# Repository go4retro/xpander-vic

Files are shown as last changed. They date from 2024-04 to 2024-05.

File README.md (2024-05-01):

# X-Pander VIC

## Introduction

Cousin to the X-Pander 3 for the C64/SX/C128/C128D, X-Pander VIC opens up a wealth of expansion options for your Commodore VIC-20/VIC-1001. This design continues on tradition of vintage designs like the CardCo Cardboard, while adding more granular controls over select lines like the CMD EX-3/EX2+1 for the C64. The X-Pander VIC offers the following features:

- Individually-selectable expansion ports
- sPower indicators for each port
- Ability to swap IO select lines ports
- Easily accessed piano-style configuration switches
- Top-loading or back-loading terminal port.
- Terminal port can accommodate 2 cartridges at the same time*
- Reset switch

\* Both top and back-loading options for terminal port share a single set of configuration switches, requiring 2 cartridges that can coexist without configuration.

## Requirements

- Commodore VIC-20 or VIC-1001

## Purchase

The current X-Pander VIC design is not yet available, but an older model (which requires some modification by the consumer can be purchased at the [RETRO Innovations Online Store](https://store.go4retro.com/non-functional-goodies/).

## Technical Details

X-Pander VIC creates a “passive” cartridge port “bus”, with switches on the following lines:

- Power (2 switches)
- IO2
- IO3
- RAM1
- RAM2
- RAM3
- BLK1
- BLK2
- BLK3
- BLK5
- AUDIO

Additionally, all ports except the first contain jumpers allowing one to “swap”  IO2 and IO3. This can be used to move a peripheral cartridge (like a  serial card or ethernet card) normally residing at IO3 to the  alternative IO3 position so that it can coexist with another IO cartridge. Jumpers are provided, but the jumper  pins can be removed and replaced with a subminiature DPDT (double pole,  double throw) switch.

## Support

Expansion port cartridges were not normally designed to coexist with  other cartridges. Thus, it is impossible to detail the nearly infinite  combinations and whether each works or not. Also, since the “bus”  places additional load on the unbuffered expansion port IO lines,  cartridges that are susceptible to signal degradation may not work with  X-Pander VIC, even when installed alone.

Some helpful hints:

- Always insert or remove X-Pander VIC with the system port off
- Clean cartridge contacts before installation
- Switches are “on” when depressed. Normally, all switches can be left in the “on” position
- IO2/IO3 swap jumpers must be moved as a pairs

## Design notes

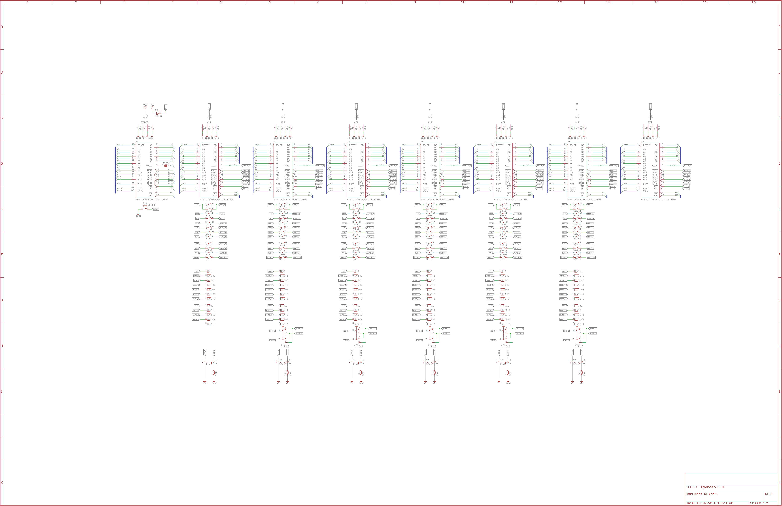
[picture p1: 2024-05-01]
pcb/Xpander6-VIC Schematic.png

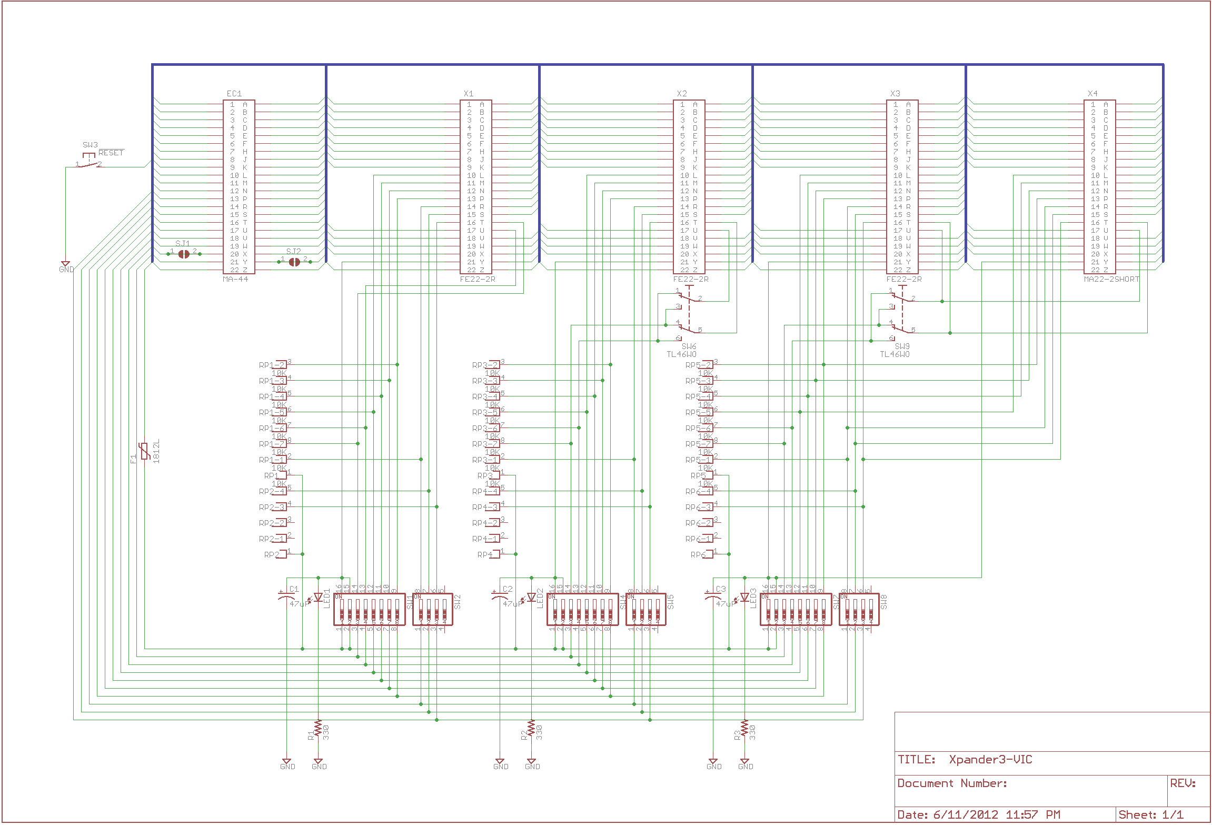
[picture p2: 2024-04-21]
pcb/Xpander3-VIC Schematic.png

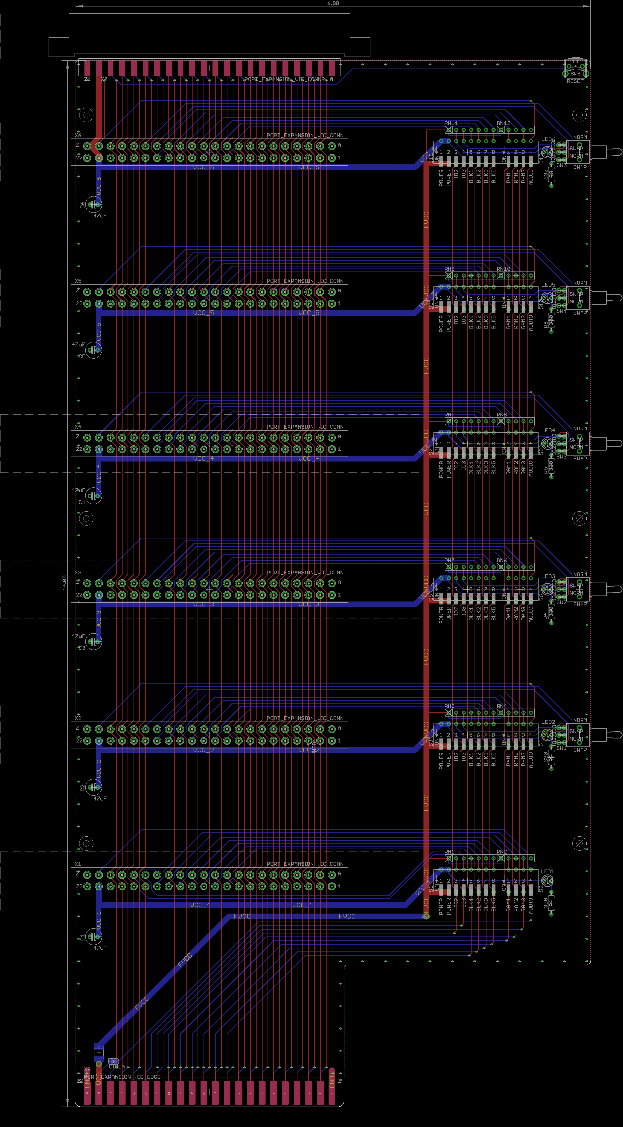
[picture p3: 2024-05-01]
pcb/Xpander6-VIC PCB.png

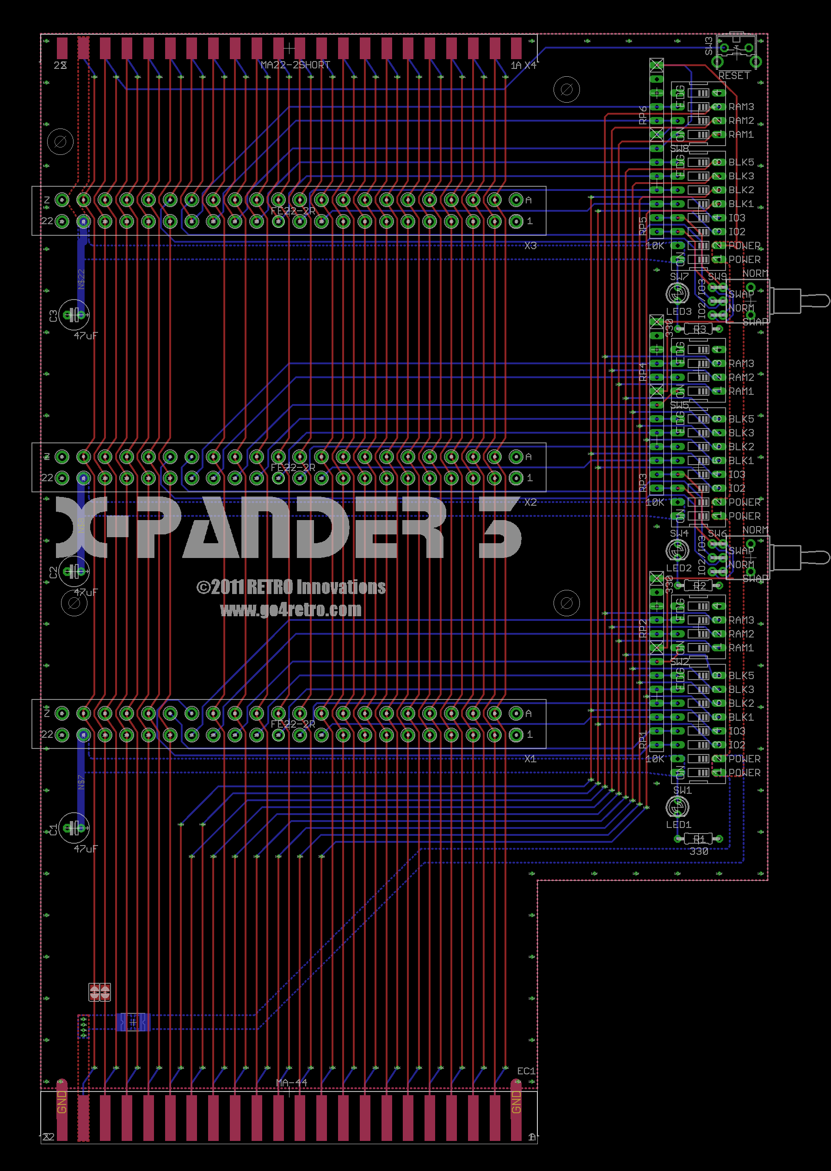
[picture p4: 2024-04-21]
pcb/Xpander3-VIC PCB.png

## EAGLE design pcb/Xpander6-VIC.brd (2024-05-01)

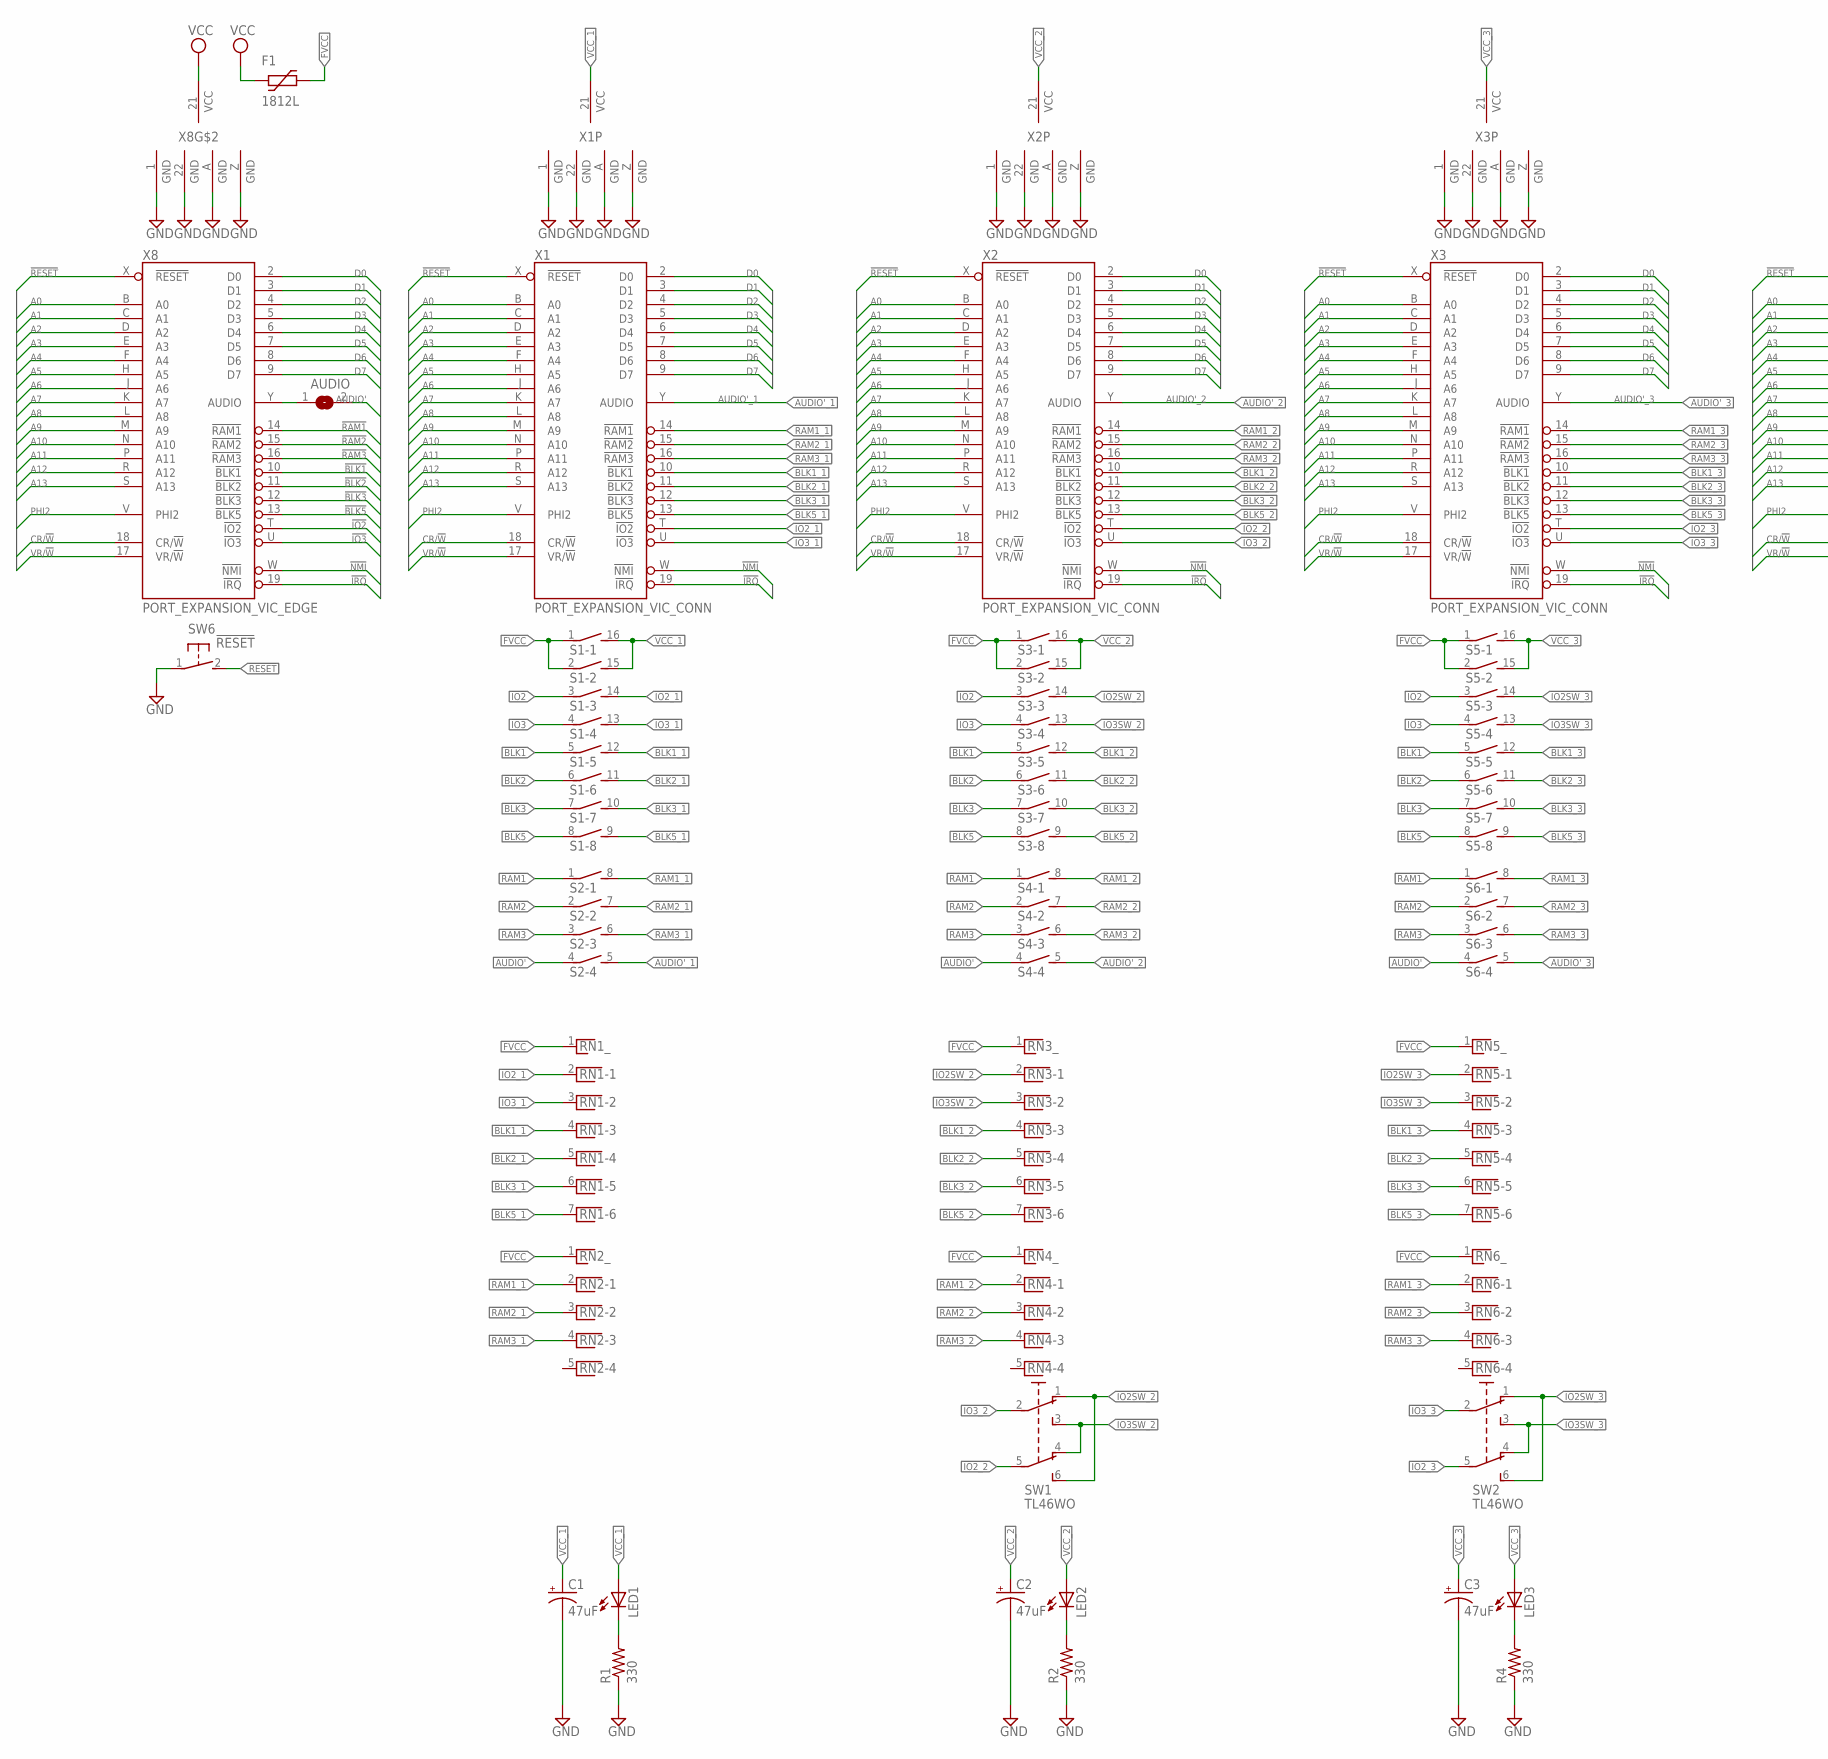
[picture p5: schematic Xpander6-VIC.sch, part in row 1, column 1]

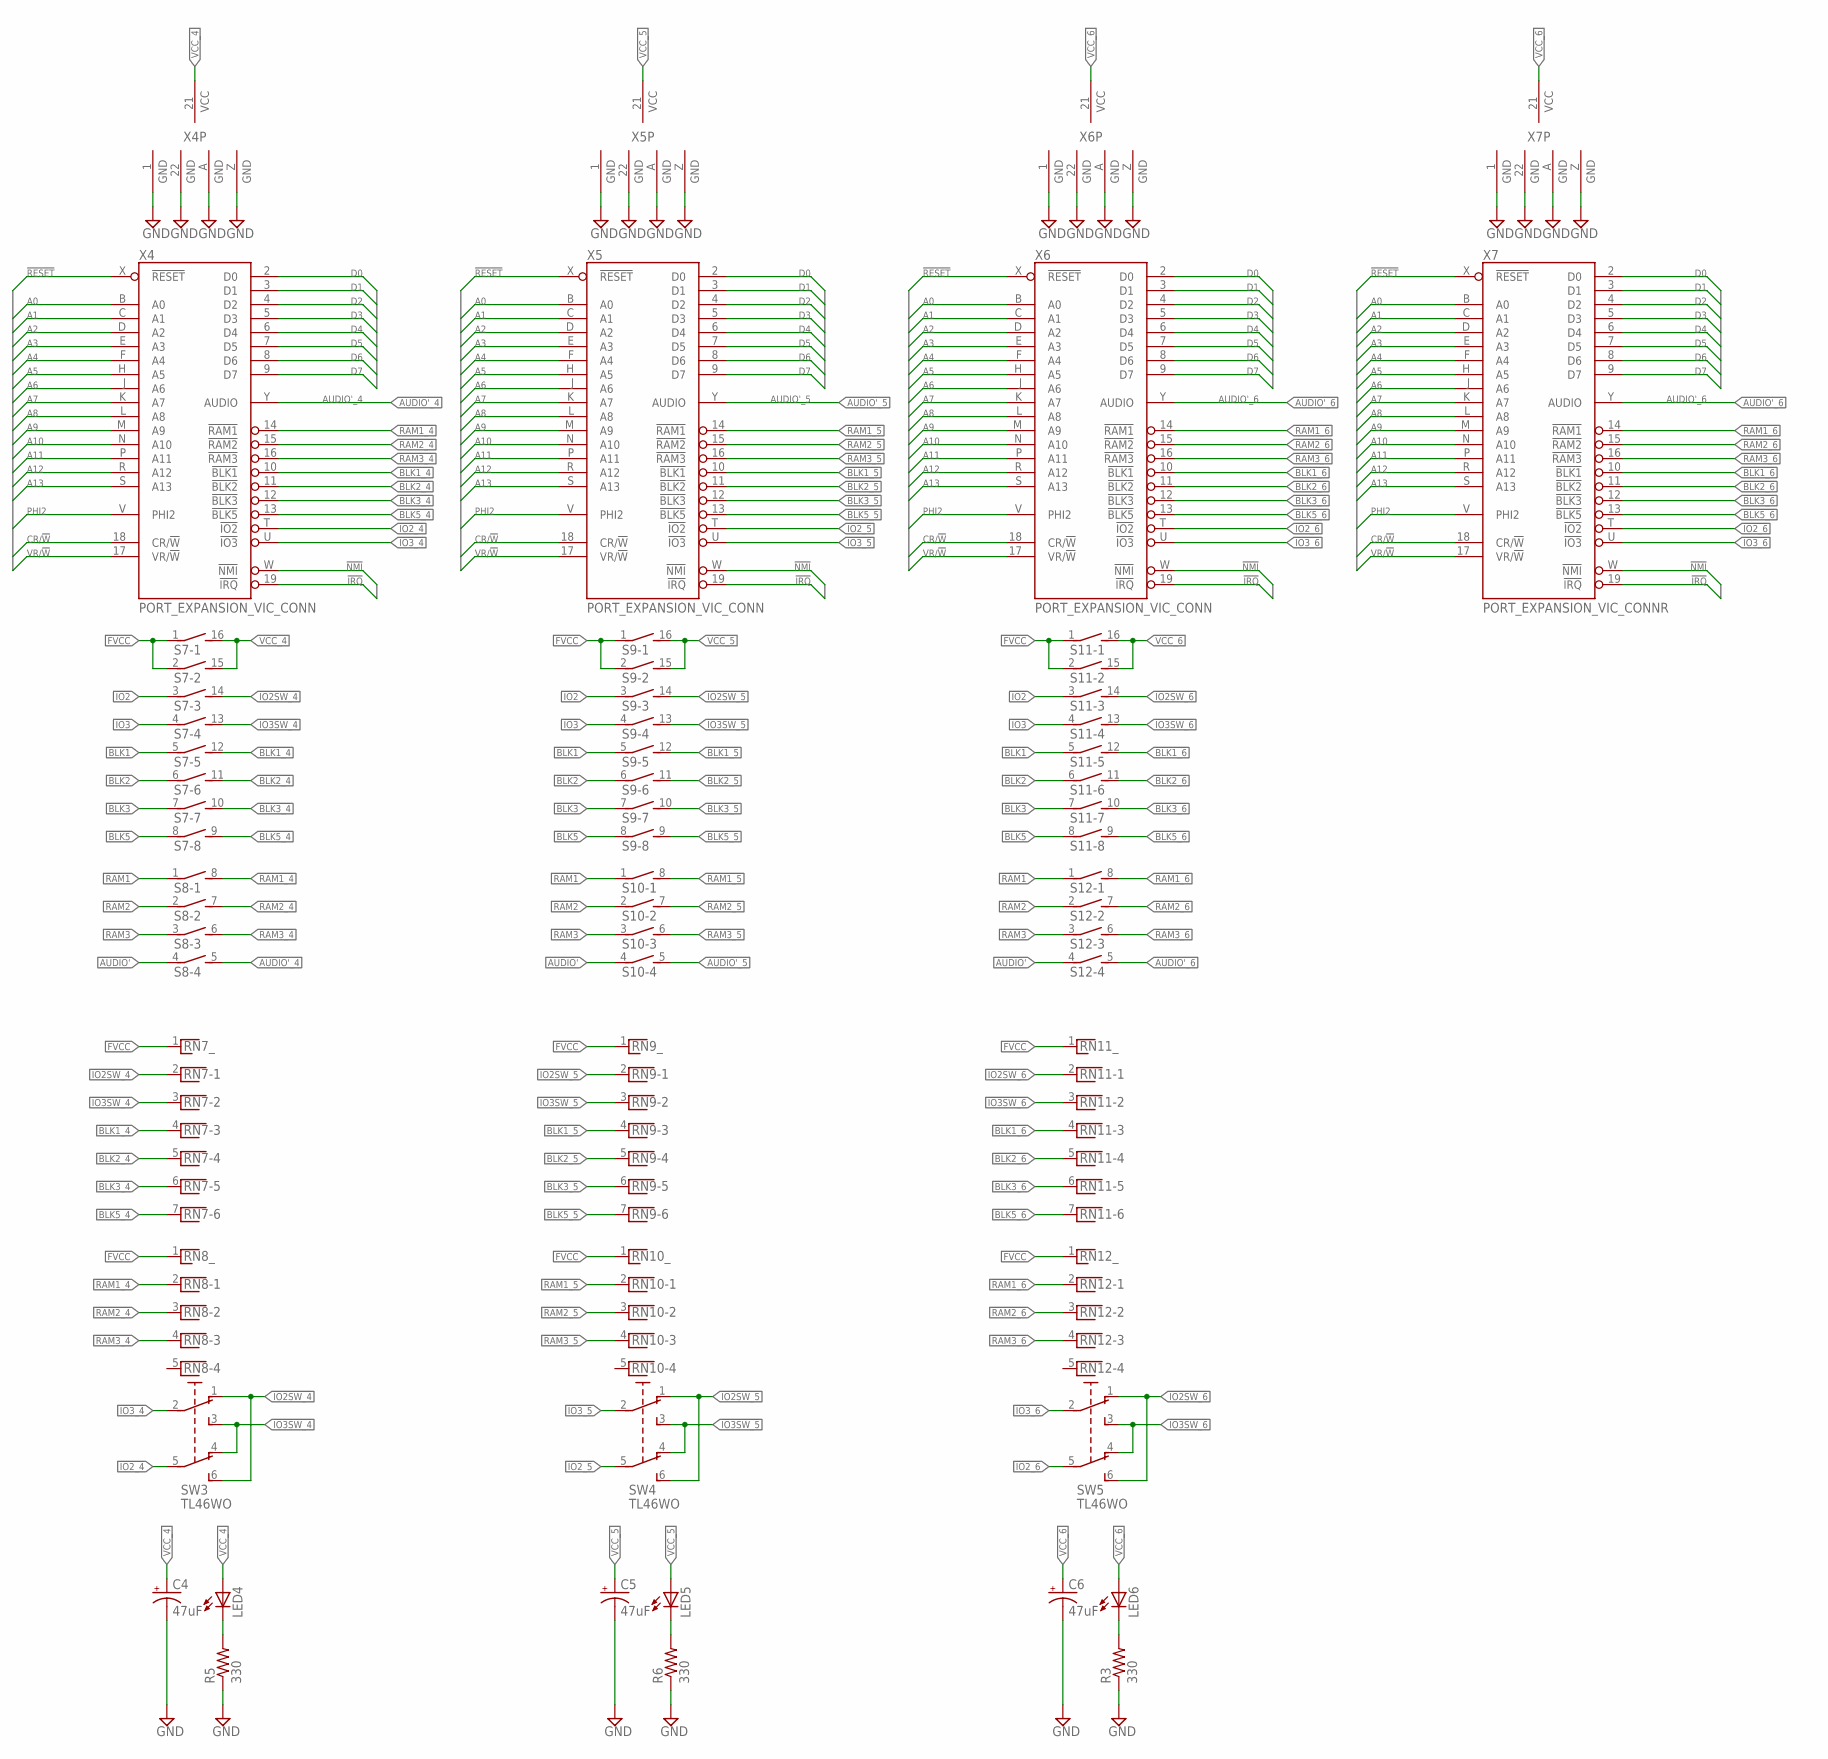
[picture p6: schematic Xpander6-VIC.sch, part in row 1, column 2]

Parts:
AUDIO: SJ
C1, C2, C3, C4, C5, C6: 47uF; E2,5-6E
F1: 1812L
LED1, LED2, LED3, LED4, LED5, LED6: LED3MM
R1, R2, R3, R4, R5, R6: 330; 0204/7
RN1, RN3, RN5, RN7, RN9, RN11: RNX6; RN-7
RN2, RN4, RN6, RN8, RN10, RN12: RNX4; RN-5
S1, S3, S5, S7, S9, S11: DIP08SB
S2, S4, S6, S8, S10, S12: DIP04SB
SW1, SW2, SW3, SW4, SW5: TL46WO; TL4XWO
SW6: !RESET; B3F-31XX
X1, X2, X3, X4, X5, X6: PORT_EXPANSION_VIC_CONN; FE156-22-2
X7: PORT_EXPANSION_VIC_CONNR; MA156-22-2SHORT
X8: PORT_EXPANSION_VIC_EDGE; MA156-22-2

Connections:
!BLK1: S1.5 (1), S3.5 (1), S5.5 (1), S7.5 (1), S9.5 (1), S11.5 (1), X8.10 (!BLK1)
!BLK1_1: RN1.4, S1.12 (2), X1.10 (!BLK1)
!BLK1_2: RN3.4, S3.12 (2), X2.10 (!BLK1)
!BLK1_3: RN5.4, S5.12 (2), X3.10 (!BLK1)
!BLK1_4: RN7.4, S7.12 (2), X4.10 (!BLK1)
!BLK1_5: RN9.4, S9.12 (2), X5.10 (!BLK1)
!BLK1_6: RN11.4, S11.12 (2), X6.10 (!BLK1), X7.10 (!BLK1)
!BLK2: S1.6 (1), S3.6 (1), S5.6 (1), S7.6 (1), S9.6 (1), S11.6 (1), X8.11 (!BLK2)
!BLK2_1: RN1.5, S1.11 (2), X1.11 (!BLK2)
!BLK2_2: RN3.5, S3.11 (2), X2.11 (!BLK2)
!BLK2_3: RN5.5, S5.11 (2), X3.11 (!BLK2)
!BLK2_4: RN7.5, S7.11 (2), X4.11 (!BLK2)
!BLK2_5: RN9.5, S9.11 (2), X5.11 (!BLK2)
!BLK2_6: RN11.5, S11.11 (2), X6.11 (!BLK2), X7.11 (!BLK2)
!BLK3: S1.7 (1), S3.7 (1), S5.7 (1), S7.7 (1), S9.7 (1), S11.7 (1), X8.12 (!BLK3)
!BLK3_1: RN1.6, S1.10 (2), X1.12 (!BLK3)
!BLK3_2: RN3.6, S3.10 (2), X2.12 (!BLK3)
!BLK3_3: RN5.6, S5.10 (2), X3.12 (!BLK3)
!BLK3_4: RN7.6, S7.10 (2), X4.12 (!BLK3)
!BLK3_5: RN9.6, S9.10 (2), X5.12 (!BLK3)
!BLK3_6: RN11.6, S11.10 (2), X6.12 (!BLK3), X7.12 (!BLK3)
!BLK5: S1.8 (1), S3.8 (1), S5.8 (1), S7.8 (1), S9.8 (1), S11.8 (1), X8.13 (!BLK5)
!BLK5_1: RN1.7, S1.9 (2), X1.13 (!BLK5)
!BLK5_2: RN3.7, S3.9 (2), X2.13 (!BLK5)
!BLK5_3: RN5.7, S5.9 (2), X3.13 (!BLK5)
!BLK5_4: RN7.7, S7.9 (2), X4.13 (!BLK5)
!BLK5_5: RN9.7, S9.9 (2), X5.13 (!BLK5)
!BLK5_6: RN11.7, S11.9 (2), X6.13 (!BLK5), X7.13 (!BLK5)
!IO2: S1.3 (1), S3.3 (1), S5.3 (1), S7.3 (1), S9.3 (1), S11.3 (1), X8.T (!IO2)
!IO2SW_2: RN3.2, S3.14 (2), SW1.1 (O), SW1.6 (S1)
!IO2SW_3: RN5.2, S5.14 (2), SW2.1 (O), SW2.6 (S1)
!IO2SW_4: RN7.2, S7.14 (2), SW3.1 (O), SW3.6 (S1)
!IO2SW_5: RN9.2, S9.14 (2), SW4.1 (O), SW4.6 (S1)
!IO2SW_6: RN11.2, S11.14 (2), SW5.1 (O), SW5.6 (S1)
!IO2_1: RN1.2, S1.14 (2), X1.T (!IO2)
!IO2_2: SW1.5 (P1), X2.T (!IO2)
!IO2_3: SW2.5 (P1), X3.T (!IO2)
!IO2_4: SW3.5 (P1), X4.T (!IO2)
!IO2_5: SW4.5 (P1), X5.T (!IO2)
!IO2_6: SW5.5 (P1), X6.T (!IO2), X7.T (!IO2)
!IO3: S1.4 (1), S3.4 (1), S5.4 (1), S7.4 (1), S9.4 (1), S11.4 (1), X8.U (!IO3)
!IO3SW_2: RN3.3, S3.13 (2), SW1.3 (S), SW1.4 (O1)
!IO3SW_3: RN5.3, S5.13 (2), SW2.3 (S), SW2.4 (O1)
!IO3SW_4: RN7.3, S7.13 (2), SW3.3 (S), SW3.4 (O1)
!IO3SW_5: RN9.3, S9.13 (2), SW4.3 (S), SW4.4 (O1)
!IO3SW_6: RN11.3, S11.13 (2), SW5.3 (S), SW5.4 (O1)
!IO3_1: RN1.3, S1.13 (2), X1.U (!IO3)
!IO3_2: SW1.2, X2.U (!IO3)
!IO3_3: SW2.2, X3.U (!IO3)
!IO3_4: SW3.2, X4.U (!IO3)
!IO3_5: SW4.2, X5.U (!IO3)
!IO3_6: SW5.2, X6.U (!IO3), X7.U (!IO3)
!IRQ: X1.19 (!IRQ), X2.19 (!IRQ), X3.19 (!IRQ), X4.19 (!IRQ), X5.19 (!IRQ), X6.19 (!IRQ), X7.19 (!IRQ), X8.19 (!IRQ)
!NMI: X1.W (!NMI), X2.W (!NMI), X3.W (!NMI), X4.W (!NMI), X5.W (!NMI), X6.W (!NMI), X7.W (!NMI), X8.W (!NMI)
!RAM1: S2.1, S4.1, S6.1, S8.1, S10.1, S12.1, X8.14 (!RAM1)
!RAM1_1: RN2.2, S2.8 (2), X1.14 (!RAM1)
!RAM1_2: RN4.2, S4.8 (2), X2.14 (!RAM1)
!RAM1_3: RN6.2, S6.8 (2), X3.14 (!RAM1)
!RAM1_4: RN8.2, S8.8 (2), X4.14 (!RAM1)
!RAM1_5: RN10.2, S10.8 (2), X5.14 (!RAM1)
!RAM1_6: RN12.2, S12.8 (2), X6.14 (!RAM1), X7.14 (!RAM1)
!RAM2: S2.2 (1), S4.2 (1), S6.2 (1), S8.2 (1), S10.2 (1), S12.2 (1), X8.15 (!RAM2)
!RAM2_1: RN2.3, S2.7 (2), X1.15 (!RAM2)
!RAM2_2: RN4.3, S4.7 (2), X2.15 (!RAM2)
!RAM2_3: RN6.3, S6.7 (2), X3.15 (!RAM2)
!RAM2_4: RN8.3, S8.7 (2), X4.15 (!RAM2)
!RAM2_5: RN10.3, S10.7 (2), X5.15 (!RAM2)
!RAM2_6: RN12.3, S12.7 (2), X6.15 (!RAM2), X7.15 (!RAM2)
!RAM3: S2.3 (1), S4.3 (1), S6.3 (1), S8.3 (1), S10.3 (1), S12.3 (1), X8.16 (!RAM3)
!RAM3_1: RN2.4, S2.6 (2), X1.16 (!RAM3)
!RAM3_2: RN4.4, S4.6 (2), X2.16 (!RAM3)
!RAM3_3: RN6.4, S6.6 (2), X3.16 (!RAM3)
!RAM3_4: RN8.4, S8.6 (2), X4.16 (!RAM3)
!RAM3_5: RN10.4, S10.6 (2), X5.16 (!RAM3)
!RAM3_6: RN12.4, S12.6 (2), X6.16 (!RAM3), X7.16 (!RAM3)
!RESET: SW6.2 (S), X1.X (!RESET), X2.X (!RESET), X3.X (!RESET), X4.X (!RESET), X5.X (!RESET), X6.X (!RESET), X7.X (!RESET), X8.X (!RESET)
A0: X1.B (A0), X2.B (A0), X3.B (A0), X4.B (A0), X5.B (A0), X6.B (A0), X7.B (A0), X8.B (A0)
A1: X1.C (A1), X2.C (A1), X3.C (A1), X4.C (A1), X5.C (A1), X6.C (A1), X7.C (A1), X8.C (A1)
A2: X1.D (A2), X2.D (A2), X3.D (A2), X4.D (A2), X5.D (A2), X6.D (A2), X7.D (A2), X8.D (A2)
A3: X1.E (A3), X2.E (A3), X3.E (A3), X4.E (A3), X5.E (A3), X6.E (A3), X7.E (A3), X8.E (A3)
A4: X1.F (A4), X2.F (A4), X3.F (A4), X4.F (A4), X5.F (A4), X6.F (A4), X7.F (A4), X8.F (A4)
A5: X1.H (A5), X2.H (A5), X3.H (A5), X4.H (A5), X5.H (A5), X6.H (A5), X7.H (A5), X8.H (A5)
A6: X1.J (A6), X2.J (A6), X3.J (A6), X4.J (A6), X5.J (A6), X6.J (A6), X7.J (A6), X8.J (A6)
A7: X1.K (A7), X2.K (A7), X3.K (A7), X4.K (A7), X5.K (A7), X6.K (A7), X7.K (A7), X8.K (A7)
A8: X1.L (A8), X2.L (A8), X3.L (A8), X4.L (A8), X5.L (A8), X6.L (A8), X7.L (A8), X8.L (A8)
A9: X1.M (A9), X2.M (A9), X3.M (A9), X4.M (A9), X5.M (A9), X6.M (A9), X7.M (A9), X8.M (A9)
A10: X1.N (A10), X2.N (A10), X3.N (A10), X4.N (A10), X5.N (A10), X6.N (A10), X7.N (A10), X8.N (A10)
A11: X1.P (A11), X2.P (A11), X3.P (A11), X4.P (A11), X5.P (A11), X6.P (A11), X7.P (A11), X8.P (A11)
A12: X1.R (A12), X2.R (A12), X3.R (A12), X4.R (A12), X5.R (A12), X6.R (A12), X7.R (A12), X8.R (A12)
A13: X1.S (A13), X2.S (A13), X3.S (A13), X4.S (A13), X5.S (A13), X6.S (A13), X7.S (A13), X8.S (A13)
AUDIO: AUDIO.1, X8.Y (AUDIO)
AUDIO': AUDIO.2, S2.4 (1), S4.4 (1), S6.4 (1), S8.4 (1), S10.4 (1), S12.4 (1)
AUDIO'_1: S2.5 (2), X1.Y (AUDIO)
AUDIO'_2: S4.5 (2), X2.Y (AUDIO)
AUDIO'_3: S6.5 (2), X3.Y (AUDIO)
AUDIO'_4: S8.5 (2), X4.Y (AUDIO)
AUDIO'_5: S10.5 (2), X5.Y (AUDIO)
AUDIO'_6: S12.5 (2), X6.Y (AUDIO), X7.Y (AUDIO)
CR/!W: X1.18 (CR/!W), X2.18 (CR/!W), X3.18 (CR/!W), X4.18 (CR/!W), X5.18 (CR/!W), X6.18 (CR/!W), X7.18 (CR/!W), X8.18 (CR/!W)
D0: X1.2 (D0), X2.2 (D0), X3.2 (D0), X4.2 (D0), X5.2 (D0), X6.2 (D0), X7.2 (D0), X8.2 (D0)
D1: X1.3 (D1), X2.3 (D1), X3.3 (D1), X4.3 (D1), X5.3 (D1), X6.3 (D1), X7.3 (D1), X8.3 (D1)
D2: X1.4 (D2), X2.4 (D2), X3.4 (D2), X4.4 (D2), X5.4 (D2), X6.4 (D2), X7.4 (D2), X8.4 (D2)
D3: X1.5 (D3), X2.5 (D3), X3.5 (D3), X4.5 (D3), X5.5 (D3), X6.5 (D3), X7.5 (D3), X8.5 (D3)
D4: X1.6 (D4), X2.6 (D4), X3.6 (D4), X4.6 (D4), X5.6 (D4), X6.6 (D4), X7.6 (D4), X8.6 (D4)
D5: X1.7 (D5), X2.7 (D5), X3.7 (D5), X4.7 (D5), X5.7 (D5), X6.7 (D5), X7.7 (D5), X8.7 (D5)
D6: X1.8 (D6), X2.8 (D6), X3.8 (D6), X4.8 (D6), X5.8 (D6), X6.8 (D6), X7.8 (D6), X8.8 (D6)
D7: X1.9 (D7), X2.9 (D7), X3.9 (D7), X4.9 (D7), X5.9 (D7), X6.9 (D7), X7.9 (D7), X8.9 (D7)
FVCC: F1.P$2 (2), RN1.1, RN2.1, RN3.1, RN4.1, RN5.1, RN6.1, RN7.1, RN8.1, RN9.1, RN10.1, RN11.1, RN12.1, S1.1, S1.2 (1), S3.1, S3.2 (1), S5.1, S5.2 (1), S7.1, S7.2 (1), S9.1, S9.2 (1), S11.1, S11.2 (1)
GND: C1.-, C2.-, C3.-, C4.-, C5.-, C6.-, R1.1, R2.1, R3.1, R4.1, R5.1, R6.1, SW6.1, X1.1 (GND), X1.22 (GND), X1.A (GND), X1.Z (GND), X2.1 (GND), X2.22 (GND), X2.A (GND), X2.Z (GND), X3.1 (GND), X3.22 (GND), X3.A (GND), X3.Z (GND), X4.1 (GND), X4.22 (GND), X4.A (GND), X4.Z (GND), X5.1 (GND), X5.22 (GND), X5.A (GND), X5.Z (GND), X6.1 (GND), X6.22 (GND), X6.A (GND), X6.Z (GND), X7.1 (GND), X7.22 (GND), X7.A (GND), X7.Z (GND), X8.1 (GND), X8.22 (GND), X8.A (GND), X8.Z (GND)
unnamed: LED1.K (C), R1.2
unnamed: LED2.K (C), R2.2
unnamed: LED6.K (C), R3.2
unnamed: LED3.K (C), R4.2
unnamed: LED4.K (C), R5.2
unnamed: LED5.K (C), R6.2
PHI2: X1.V (PHI2), X2.V (PHI2), X3.V (PHI2), X4.V (PHI2), X5.V (PHI2), X6.V (PHI2), X7.V (PHI2), X8.V (PHI2)
VCC: F1.P$1 (1), X8.21 (VCC)
VCC_1: C1.+, LED1.A, S1.15 (2), S1.16 (2), X1.21 (VCC)
VCC_2: C2.+, LED2.A, S3.15 (2), S3.16 (2), X2.21 (VCC)
VCC_3: C3.+, LED3.A, S5.15 (2), S5.16 (2), X3.21 (VCC)
VCC_4: C4.+, LED4.A, S7.15 (2), S7.16 (2), X4.21 (VCC)
VCC_5: C5.+, LED5.A, S9.15 (2), S9.16 (2), X5.21 (VCC)
VCC_6: C6.+, LED6.A, S11.15 (2), S11.16 (2), X6.21 (VCC), X7.21 (VCC)
VR/!W: X1.17 (VR/!W), X2.17 (VR/!W), X3.17 (VR/!W), X4.17 (VR/!W), X5.17 (VR/!W), X6.17 (VR/!W), X7.17 (VR/!W), X8.17 (VR/!W)

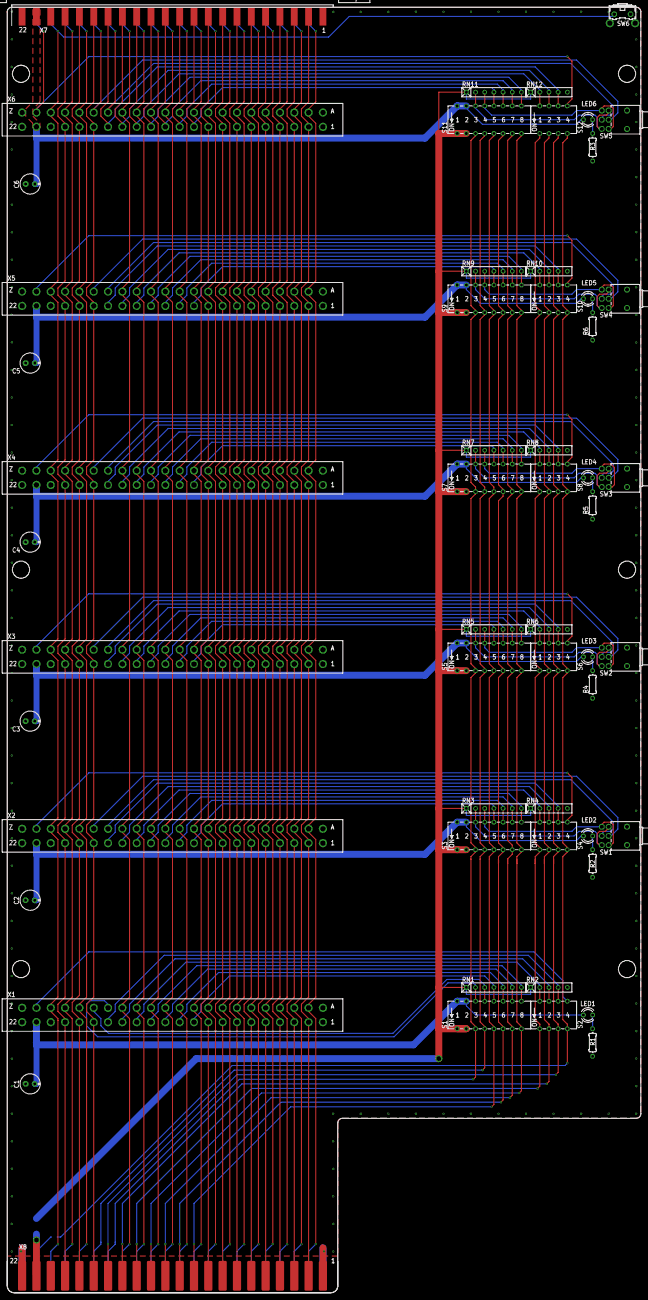
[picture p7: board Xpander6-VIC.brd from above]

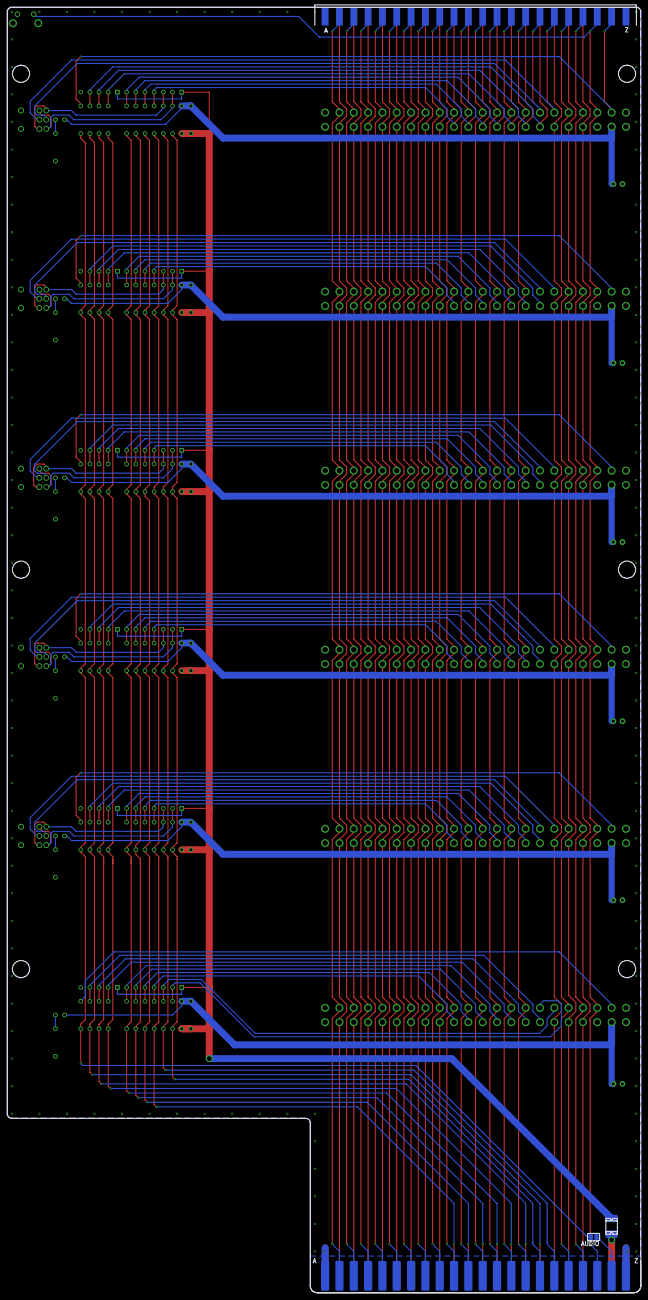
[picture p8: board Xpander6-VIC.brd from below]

Board: 2 copper layers, 175.3 x 355.6 mm, 58 parts (2 on the bottom side), 124 nets.

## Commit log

2024-04-21 v1 design
    [Xpander3-VIC.brd, Xpander3-VIC.sch]
2024-04-21 v1.1 design (switches are still too close)
    [Xpander3-VIC.brd, Xpander3-VIC.sch]
2024-04-21 Add 6 slot variant (still need to reduce slot pitch)
    [Xpander6-VIC.brd, Xpander6-VIC.sch]
2024-04-21 Convert 6 slot design to use newer symbols
    [Xpander6-VIC.brd, Xpander6-VIC.sch]
2024-04-21 Route optional audio line
    [Xpander6-VIC.brd, Xpander6-VIC.sch]
2024-04-21 Add images
    [Xpander6-VIC.brd]
2024-05-01 More updates
    [Xpander6-VIC.brd, Xpander6-VIC.sch]
